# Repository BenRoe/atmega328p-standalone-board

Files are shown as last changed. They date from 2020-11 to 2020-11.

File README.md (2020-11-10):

# 328p-Standalone-TH

Development board for the Atmega328P with USB-C connector and only through hole components.  
It's very handy to flash the bootloader on many Atmega328P IC's.

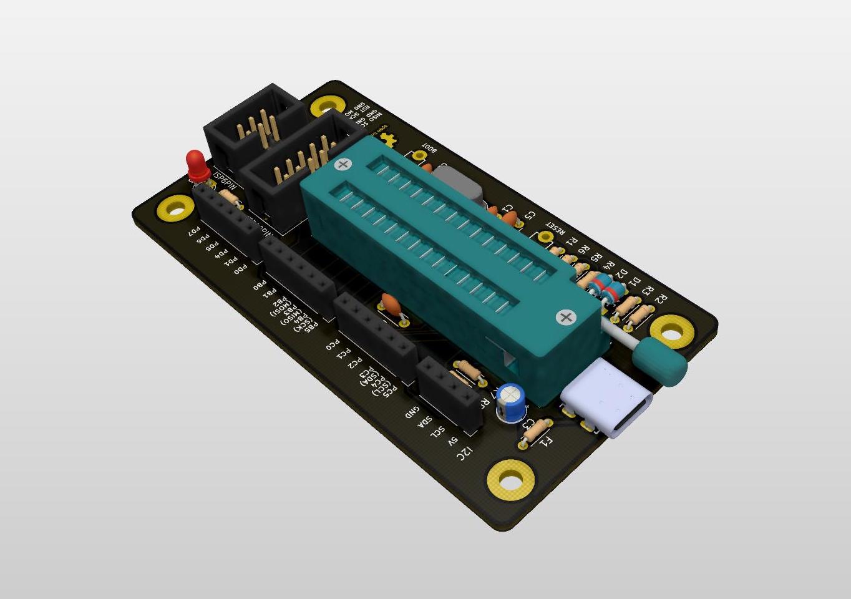
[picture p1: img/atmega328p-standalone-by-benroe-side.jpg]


## Features

- ISP 6/10 header for bootloader flashing (recommend [USBaspLoader](https://github.com/baerwolf/USBaspLoader))
- USB-C connector (if USBaspLoader bootloader is on the Atmega328P, you can flash the firmware via USB)
- ISP activity led (MISO Pin)
- Boot/Reset switch
- [ZIF](https://en.wikipedia.org/wiki/Zero_insertion_force) socket for easy MCU swap
  
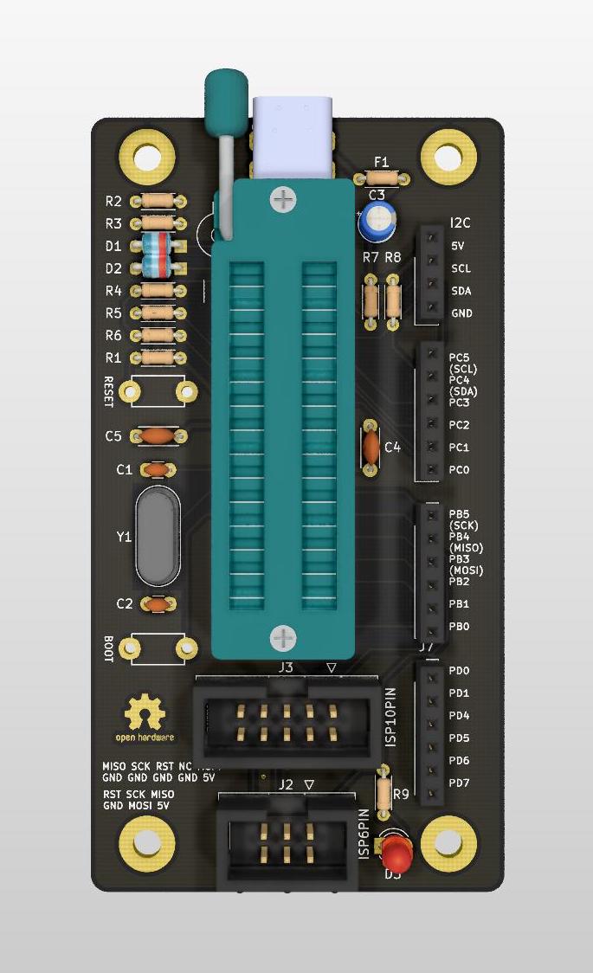
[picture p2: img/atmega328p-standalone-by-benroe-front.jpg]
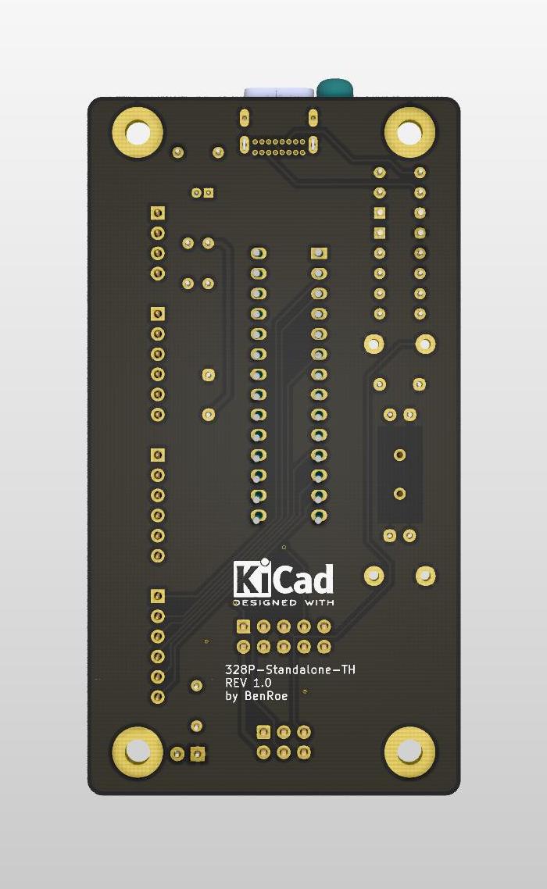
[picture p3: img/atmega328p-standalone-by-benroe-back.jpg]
 

- [Schematic](schematic.pdf)
- [BOM](http://htmlpreview.github.io/?https://github.com/BenRoe/atmega328p-standalone-board/blob/master/bom/ibom.html)
- [Gerber files](gerber/328p-standalone-rev1.0.zip) (ready to use)

## License


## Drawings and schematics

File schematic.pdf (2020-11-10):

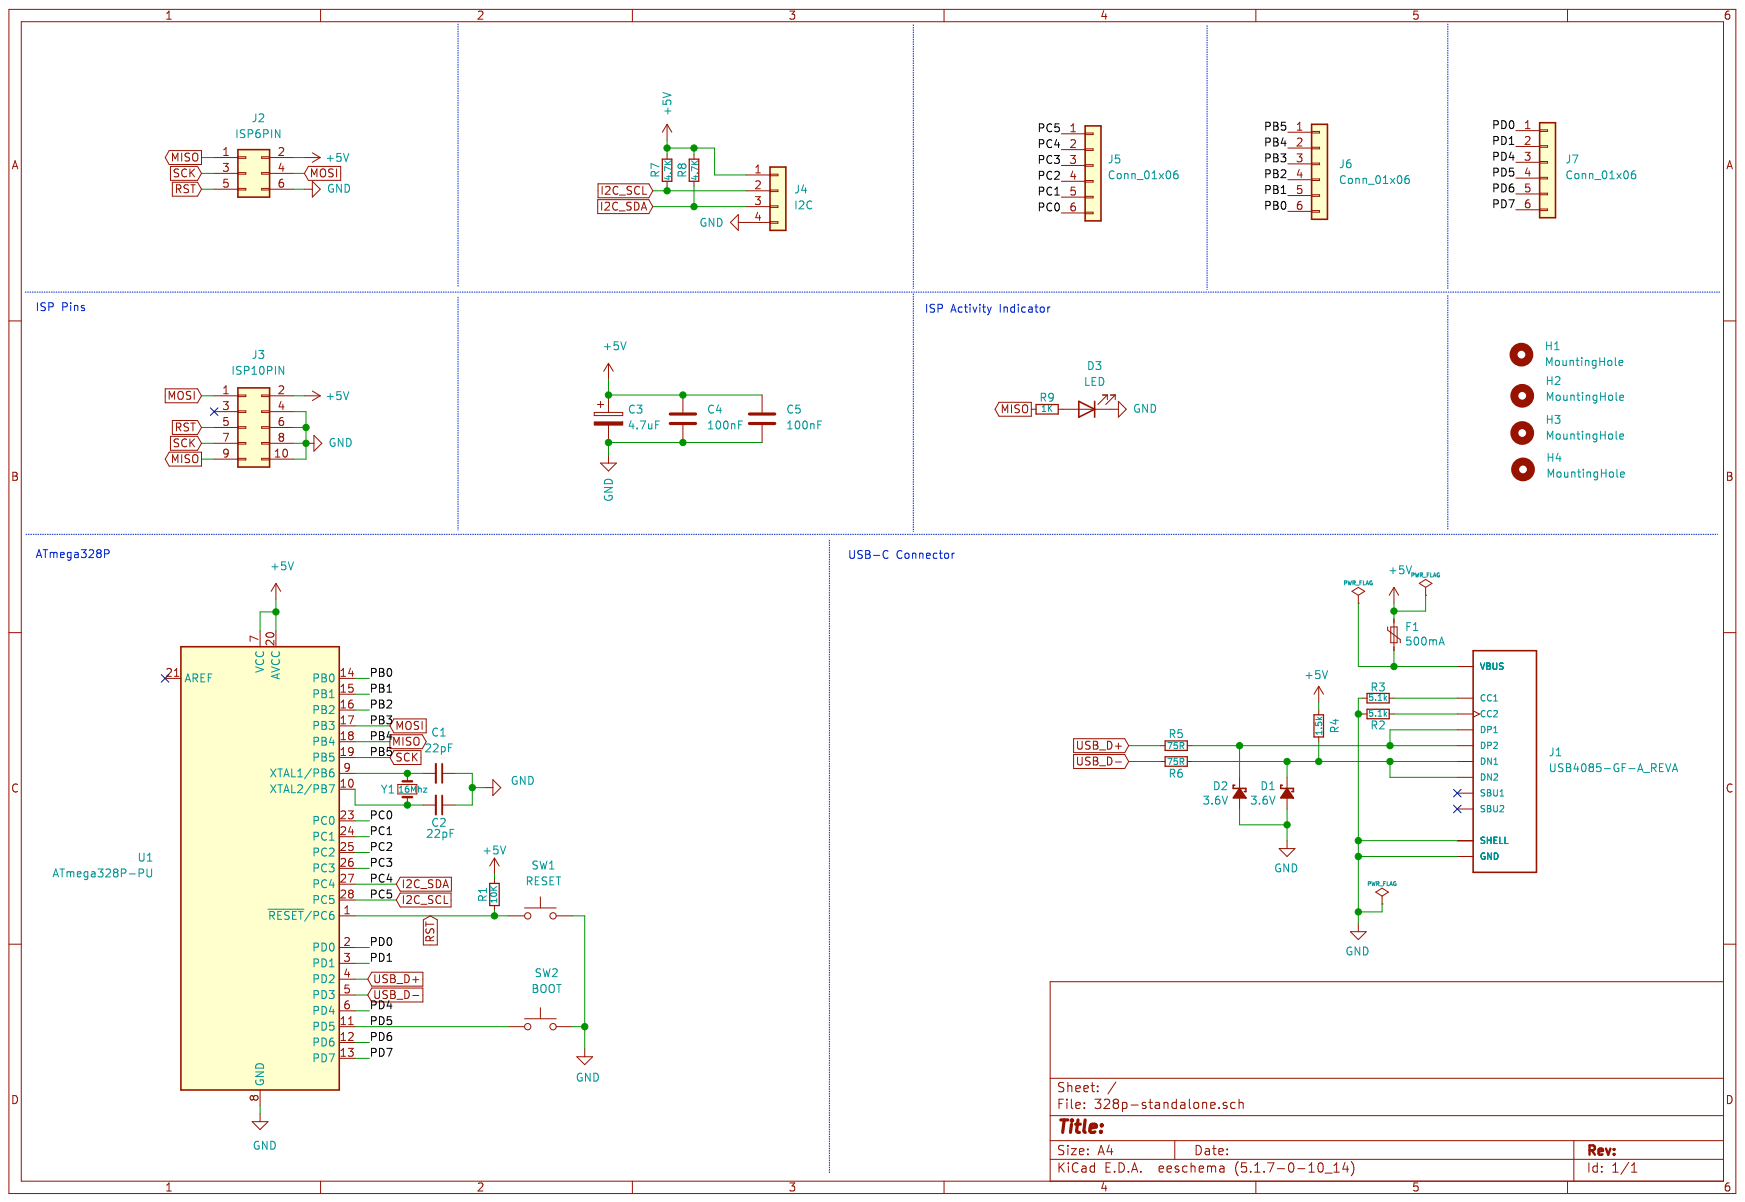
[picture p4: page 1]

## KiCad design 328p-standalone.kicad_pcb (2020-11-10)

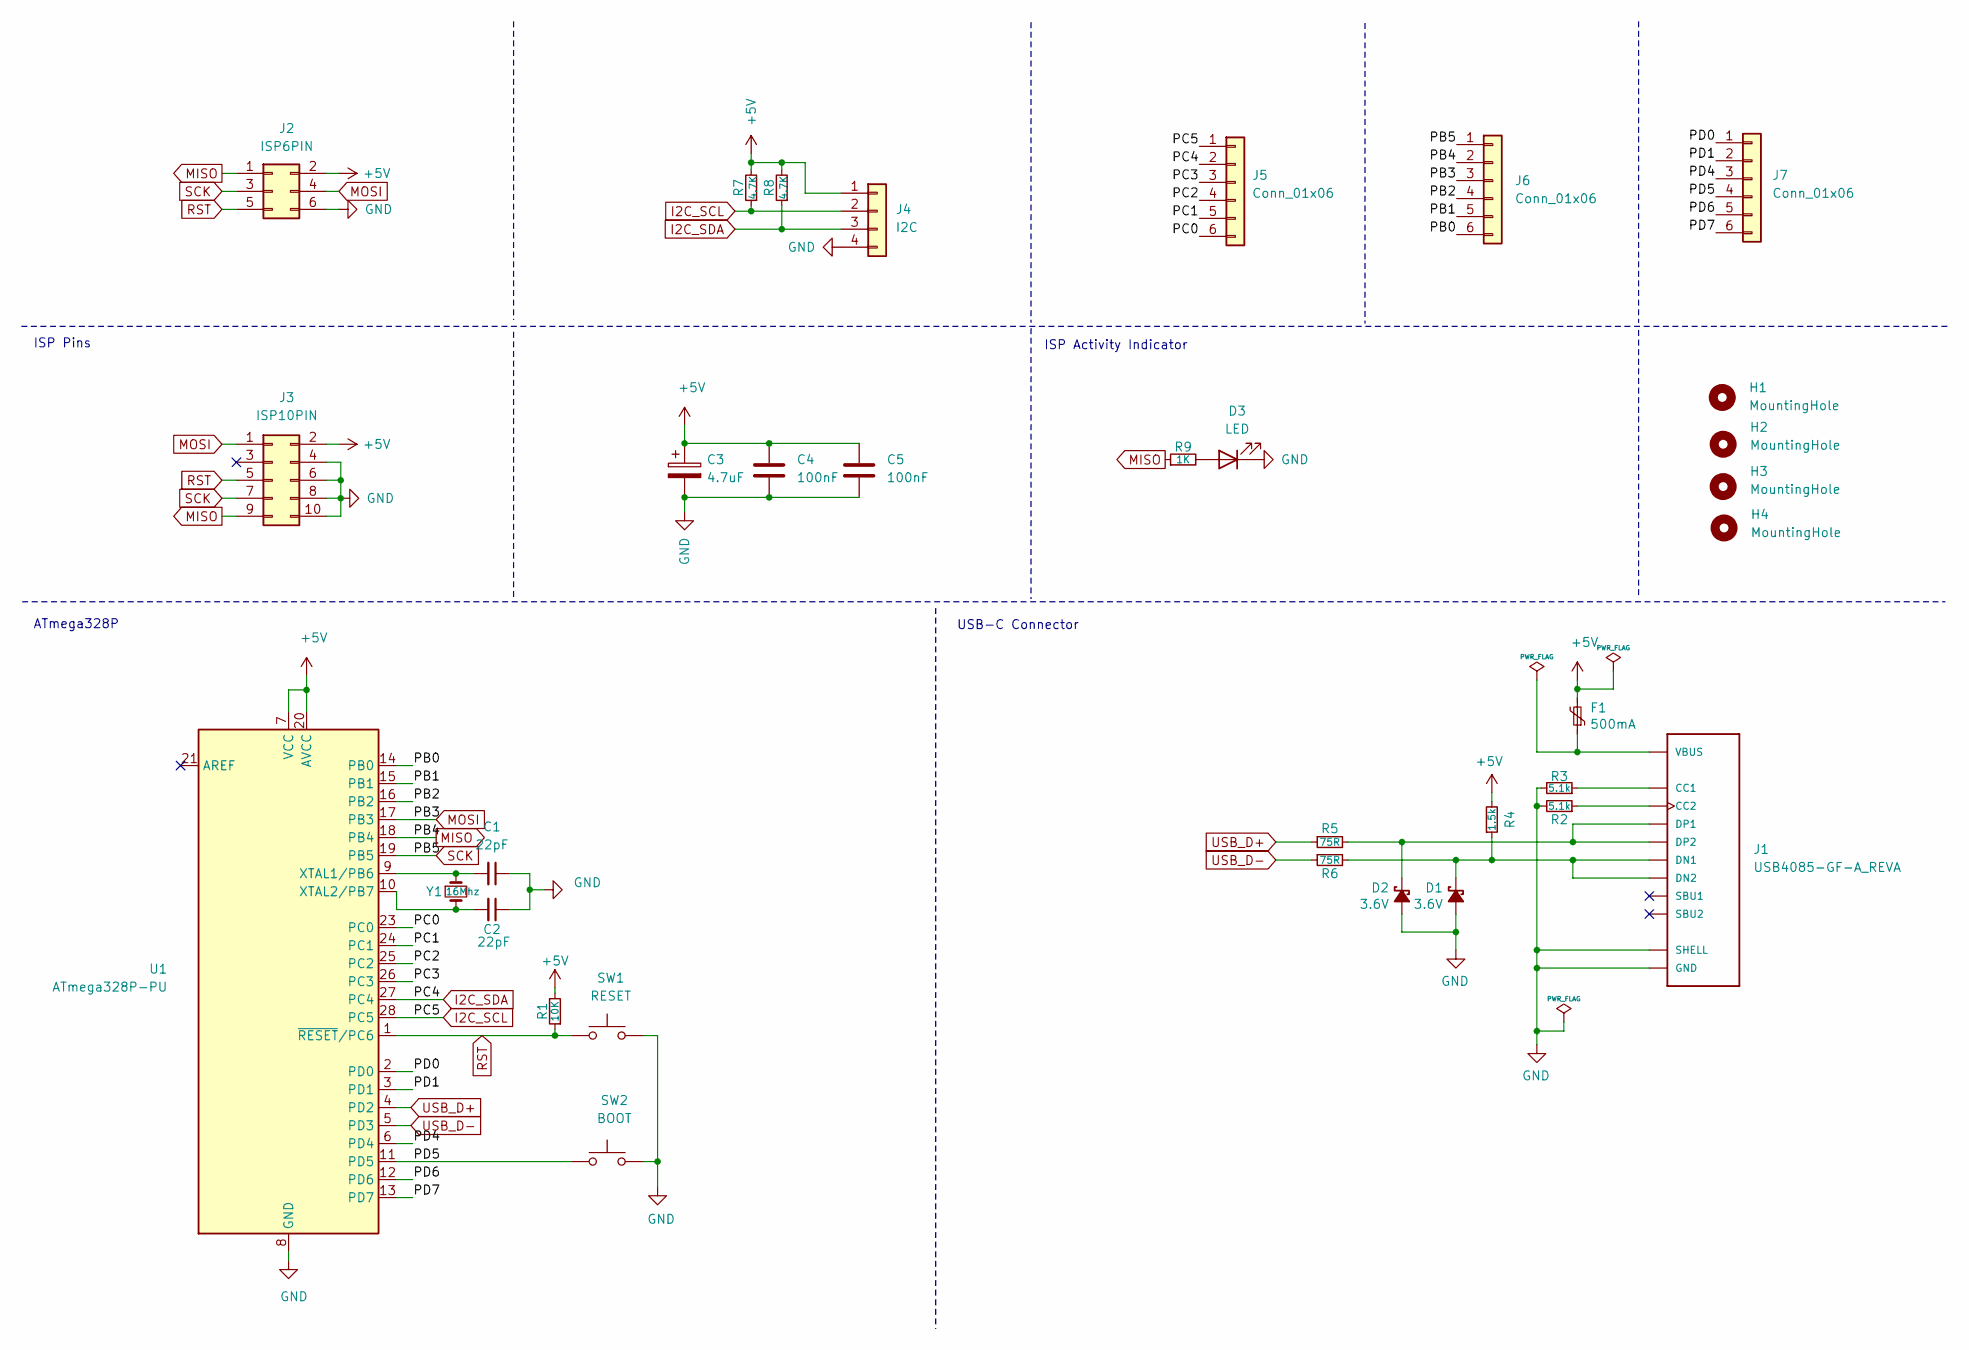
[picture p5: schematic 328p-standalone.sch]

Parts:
C1, C2: 22pF; C_Disc_D3.0mm_W1.6mm_P2.50mm
C3: 4.7uF; CP_Radial_D4.0mm_P1.50mm
C4, C5: 100nF; C_Disc_D4.3mm_W1.9mm_P5.00mm
D1, D2: 3.6V; Diode-Zener-35_SOD27_P5.08mm_Horizontal
D3: LED; LED_D3.0mm
F1: 500mA; R_Axial_DIN0204_L3.6mm_D1.6mm_P5.08mm_Horizontal
H1, H2, H3, H4: MountingHole; MountingHole_3.2mm_M3_Pad
J1: USB4085-GF-A_REVA; GCT_USB4085-GF-A_REVA
J2: ISP6PIN; IDC-Header_2x03_P2.54mm_Vertical
J3: ISP10PIN; IDC-Header_2x05_P2.54mm_Vertical
J4: I2C; PinSocket_1x04_P2.54mm_Vertical
J5, J6, J7: Conn_01x06; PinSocket_1x06_P2.54mm_Vertical
R1: 10K; R_Axial_DIN0204_L3.6mm_D1.6mm_P5.08mm_Horizontal
R2, R3: 5.1k; R_Axial_DIN0204_L3.6mm_D1.6mm_P5.08mm_Horizontal
R4: 1.5k; R_Axial_DIN0204_L3.6mm_D1.6mm_P5.08mm_Horizontal
R5, R6: 75R; R_Axial_DIN0204_L3.6mm_D1.6mm_P5.08mm_Horizontal
R7, R8: 4.7K; R_Axial_DIN0204_L3.6mm_D1.6mm_P5.08mm_Horizontal
R9: 1K; R_Axial_DIN0204_L3.6mm_D1.6mm_P5.08mm_Horizontal
SW1: RESET; TACT_SWITCH_TVBP06
SW2: BOOT; TACT_SWITCH_TVBP06
U1: ATmega328P-PU; DIP_Socket-28_ZIF-228-3341_7.62mm-row-spacing
Y1: 16Mhz; Crystal_HC49-4H_Vertical

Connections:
+5V: C3.1, C4.1, C5.1, F1.2, J2.2, J3.2, J4.1, R1.2, R4.2, R7.2, R8.2, U1.7 (VCC), U1.20 (AVCC)
/PB0: J6.6, U1.14 (PB0)
/PB1: J6.5, U1.15 (PB1)
/PB2: J6.4, U1.16 (PB2)
/PC0: J5.6, U1.23 (PC0)
/PC1: J5.5, U1.24 (PC1)
/PC2: J5.4, U1.25 (PC2)
/PC3: J5.3, U1.26 (PC3)
/PD0: J7.1, U1.2 (PD0)
/PD1: J7.2, U1.3 (PD1)
/PD4: J7.3, U1.6 (PD4)
/PD5: J7.4, SW2.1, U1.11 (PD5)
/PD6: J7.5, U1.12 (PD6)
/PD7: J7.6, U1.13 (PD7)
GND: C1.1, C2.1, C3.2, C4.2, C5.2, D1.2 (A), D2.2 (A), D3.1 (K), J1.A1 (GND), J1.A12 (GND), J1.B1 (GND), J1.B12 (GND), J1.P1 (SHELL), J1.P2 (SHELL), J1.P3 (SHELL), J1.P4 (SHELL), J2.6, J3.4, J3.6, J3.8, J3.10, J4.4, R2.2, R3.2, SW1.2, SW2.2, U1.8 (GND), U1.22 (GND)
I2C_SCL: J4.2, J5.1, R7.1, U1.28 (PC5)
I2C_SDA: J4.3, J5.2, R8.1, U1.27 (PC4)
MISO: J2.1, J3.9, J6.2, R9.1, U1.18 (PB4)
MOSI: J2.4, J3.1, J6.3, U1.17 (PB3)
unnamed: C1.2, U1.9 (XTAL1/PB6), Y1.1
unnamed: C2.2, U1.10 (XTAL2/PB7), Y1.2
unnamed: D1.1 (K), J1.A7 (DN1), J1.B7 (DN2), R4.1, R6.2
unnamed: D2.1 (K), J1.A6 (DP1), J1.B6 (DP2), R5.2
unnamed: D3.2 (A), R9.2
unnamed: F1.1, J1.A4 (VBUS), J1.A9 (VBUS), J1.B4 (VBUS), J1.B9 (VBUS)
unnamed: J1.A5 (CC1), R3.1
unnamed: J1.B5 (CC2), R2.1
RST: J2.5, J3.5, R1.1, SW1.1, U1.1 (~RESET~/PC6)
SCK: J2.3, J3.7, J6.1, U1.19 (PB5)
USB_D+: R5.1, U1.4 (PD2)
USB_D-: R6.1, U1.5 (PD3)

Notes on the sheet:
ATmega328P
ISP Pins
USB-C Connector
ISP Activity Indicator

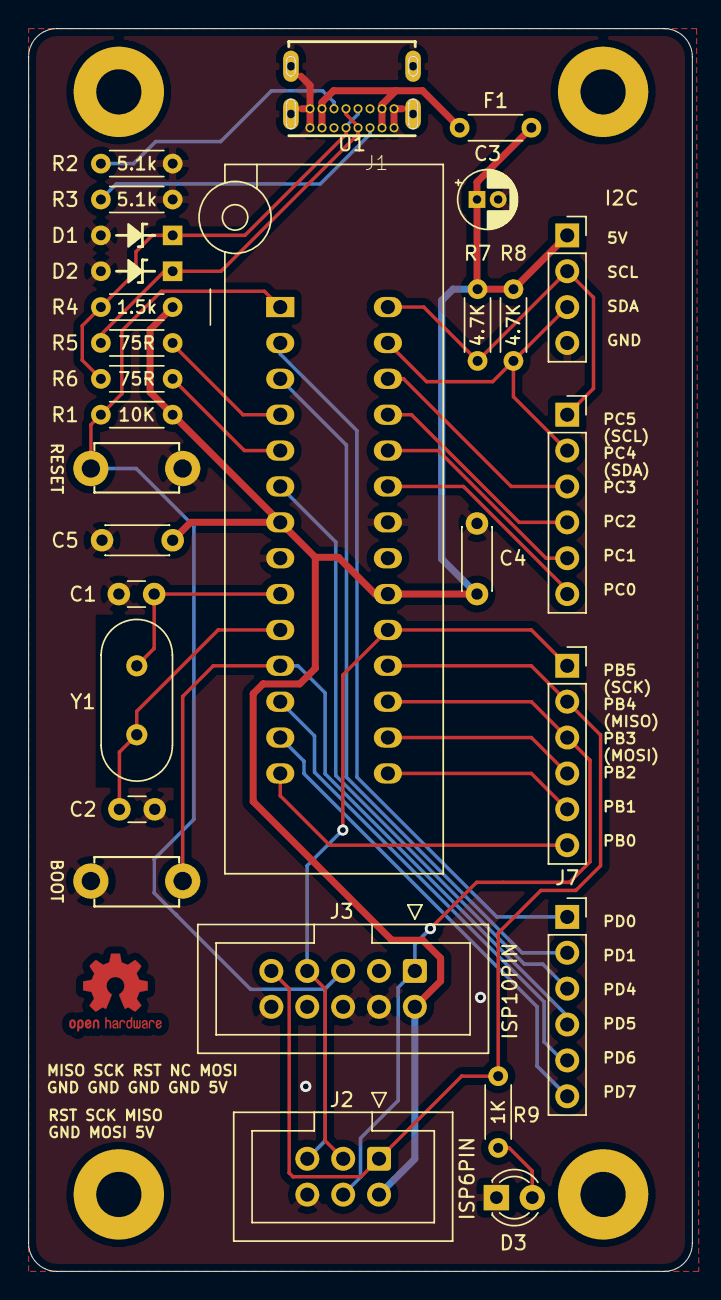
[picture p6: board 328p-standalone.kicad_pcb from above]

Board: 2 copper layers, 47.0 x 88.0 mm, 33 parts (0 on the bottom side), 31 nets.

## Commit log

2020-08-27 add gitignore file for kicad
2020-11-10 add kicad and gerber files
    [328p-standalone-B_Cu.gbl, 328p-standalone-B_Mask.gbs, 328p-standalone-B_SilkS.gbo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]
2020-11-10 add schematic link to readme

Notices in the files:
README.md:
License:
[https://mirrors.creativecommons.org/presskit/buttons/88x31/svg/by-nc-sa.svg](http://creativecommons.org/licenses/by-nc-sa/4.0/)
